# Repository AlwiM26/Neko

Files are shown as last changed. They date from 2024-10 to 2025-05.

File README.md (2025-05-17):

# Neko

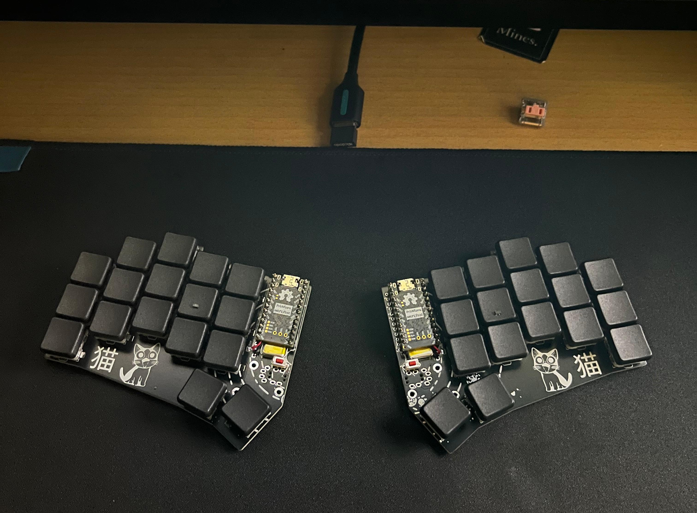
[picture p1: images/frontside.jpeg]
Neko keyboard


A custom version of the [Chocofi keyboard](https://github.com/pashutk/chocofi). With slightly different edge cut and added custom silkscreen.

## List of changes

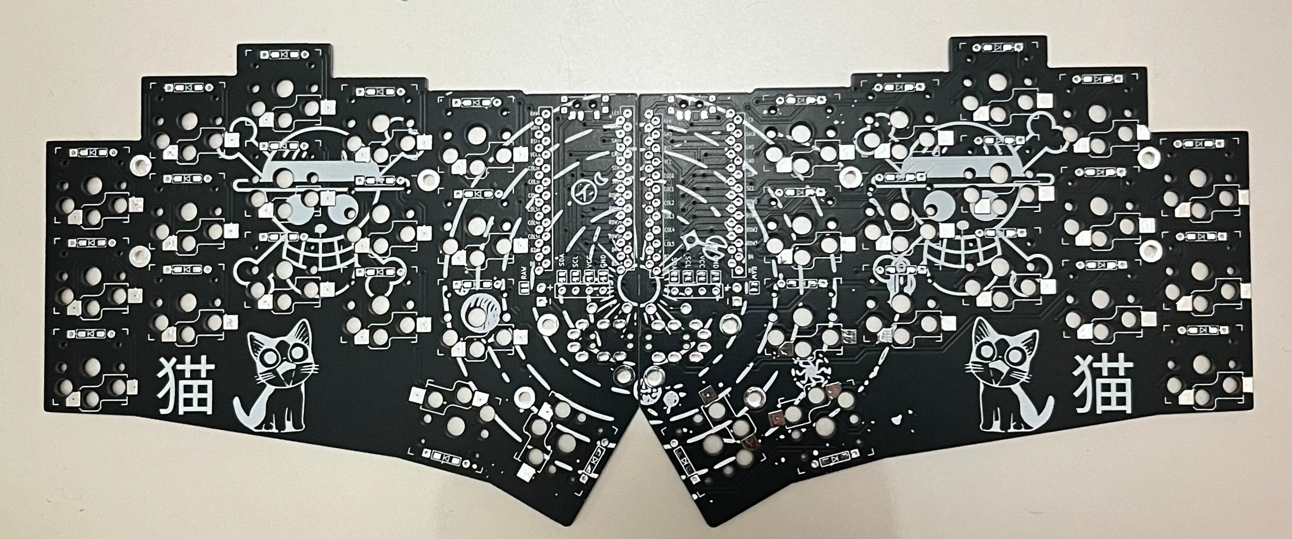
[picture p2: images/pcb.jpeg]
Neko pcb


- Slight change from the original edge cut
- Remove the inner ( 3rd ) thumb key
- Add some graphic for the silkscreen

## Assembly

- Solder all the diode on the bottom side, make sure to solder it to the correct orientation like this
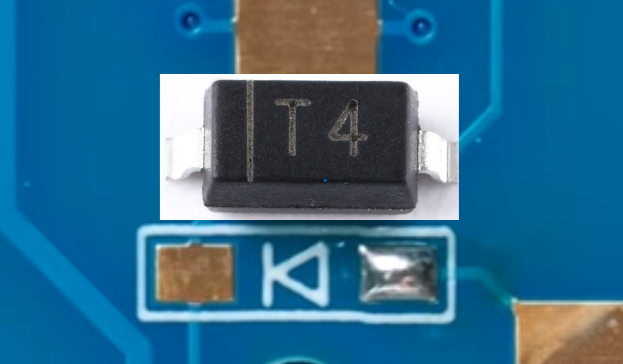
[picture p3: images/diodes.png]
Diode orientation
  
- Solder all the kailh hotswap socket on the bottom side
- ( Optional for **wireless** build )Solder power switch on the bottom side, after that, make sure to switch it off so that nothing happen when we solder the battery
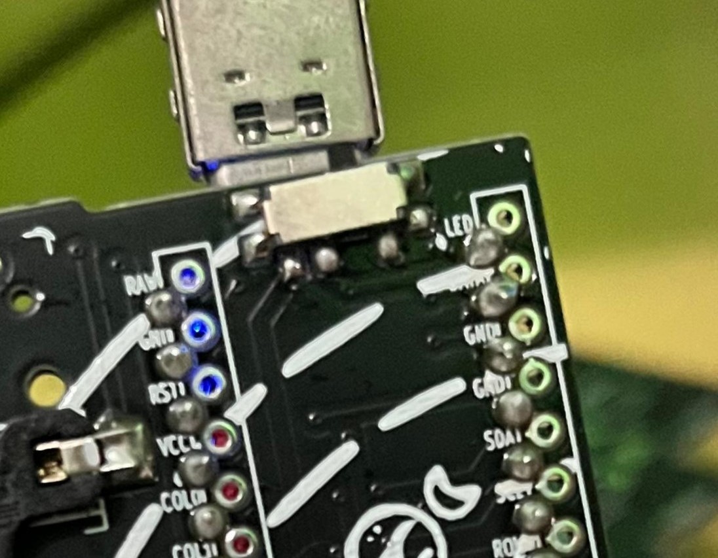
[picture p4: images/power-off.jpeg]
Power switch
  
- Solder the reset switch on the top side
- ( Optional for **wired** build) Solder the TRRS connector on the top side
- Solder the controller hotswap socket on the top side
- Solder the hotswap pin to the controller
- Remove the controller from the hotswap socket
- ( Optional for **wireless** build ) _Carefully_ solder battery wires to the connector, ensuring not to short the wires together, secure the other wire with masking tape, solder the black wire to the negative pad, and red wire to the positive pad
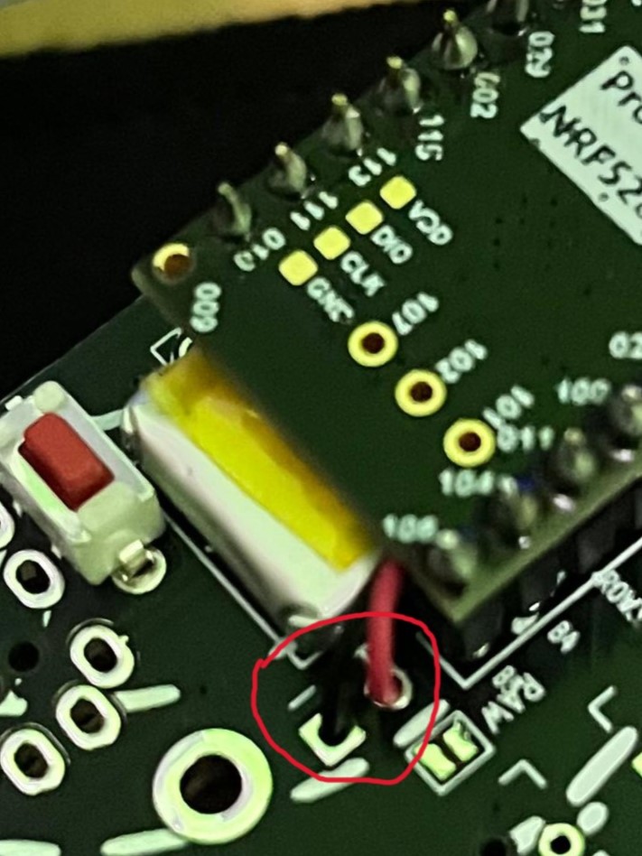
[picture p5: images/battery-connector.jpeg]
Battery socket
  
- ( Optional for **wireless** build ) Solder the battery Jumper ( labeled as RAW ) on the bottom side
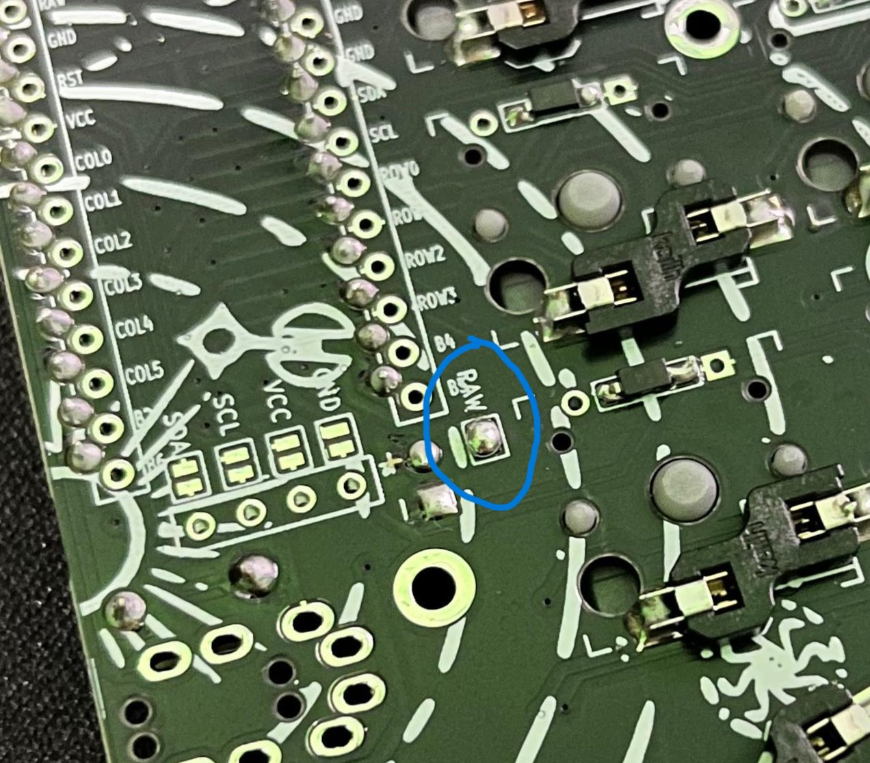
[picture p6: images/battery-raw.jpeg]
RAW
  

If you using a wireless controller, you can download my firmware [here](https://github.com/AlwiM26/zmk-config-neko/actions), or you can build your own firmware using the [ZMK firmware](https://zmk.dev), and edit the keymap using the [Keymap editor](https://nickcoutsos.github.io/keymap-editor/) by Nickcoutsos. If you using a wired controller, you can use [QMK firmware](https://qmk.fm/), and edit the layout using [Via app](https://www.caniusevia.com/)

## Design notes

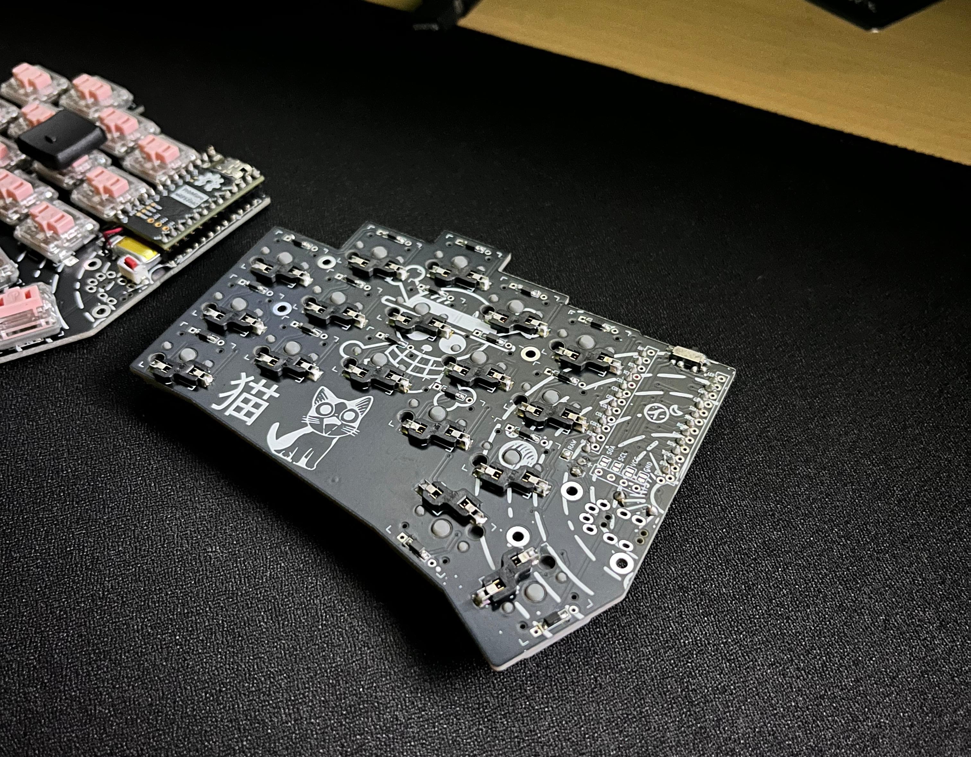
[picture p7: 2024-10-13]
images/backside.jpeg

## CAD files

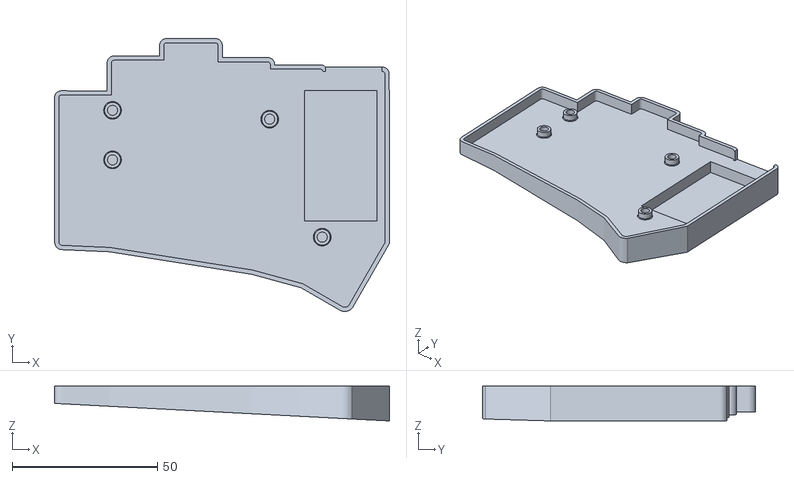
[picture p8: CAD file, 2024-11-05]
case/neko-battery-left.stl
115.2 x 93.8 x 12.0

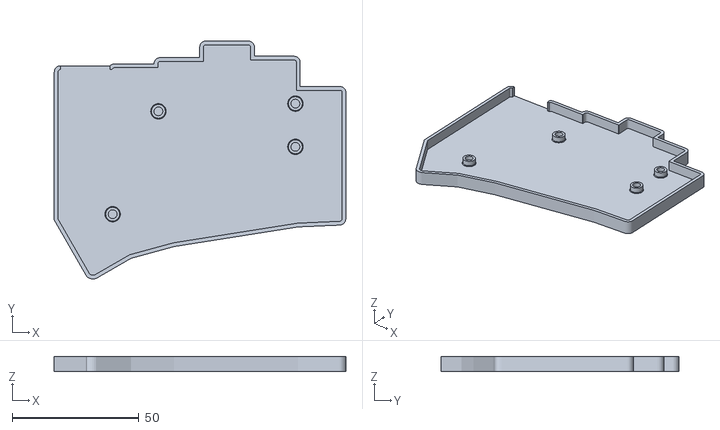
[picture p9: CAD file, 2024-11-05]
case/neko-right.stl
115.2 x 93.8 x 6.00

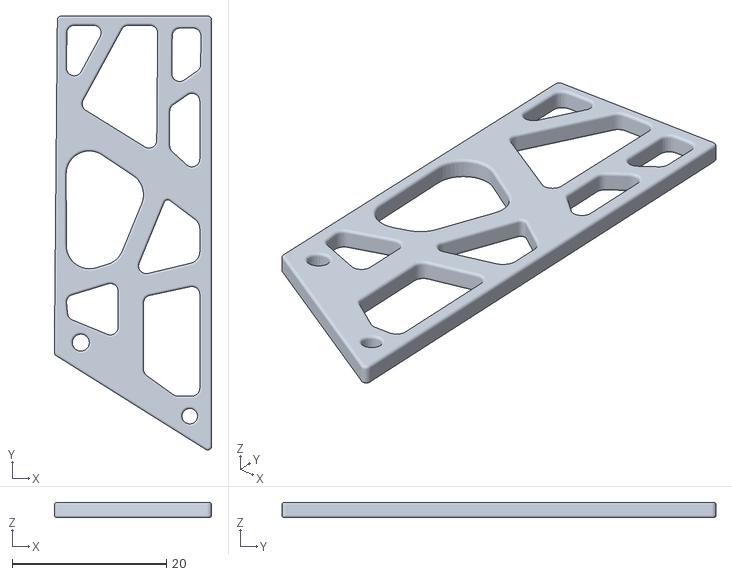
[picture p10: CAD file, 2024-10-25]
case/neko-cover.stl
20.4 x 56.2 x 2.00

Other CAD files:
case/neko-battery-right.stl
case/neko-left.stl

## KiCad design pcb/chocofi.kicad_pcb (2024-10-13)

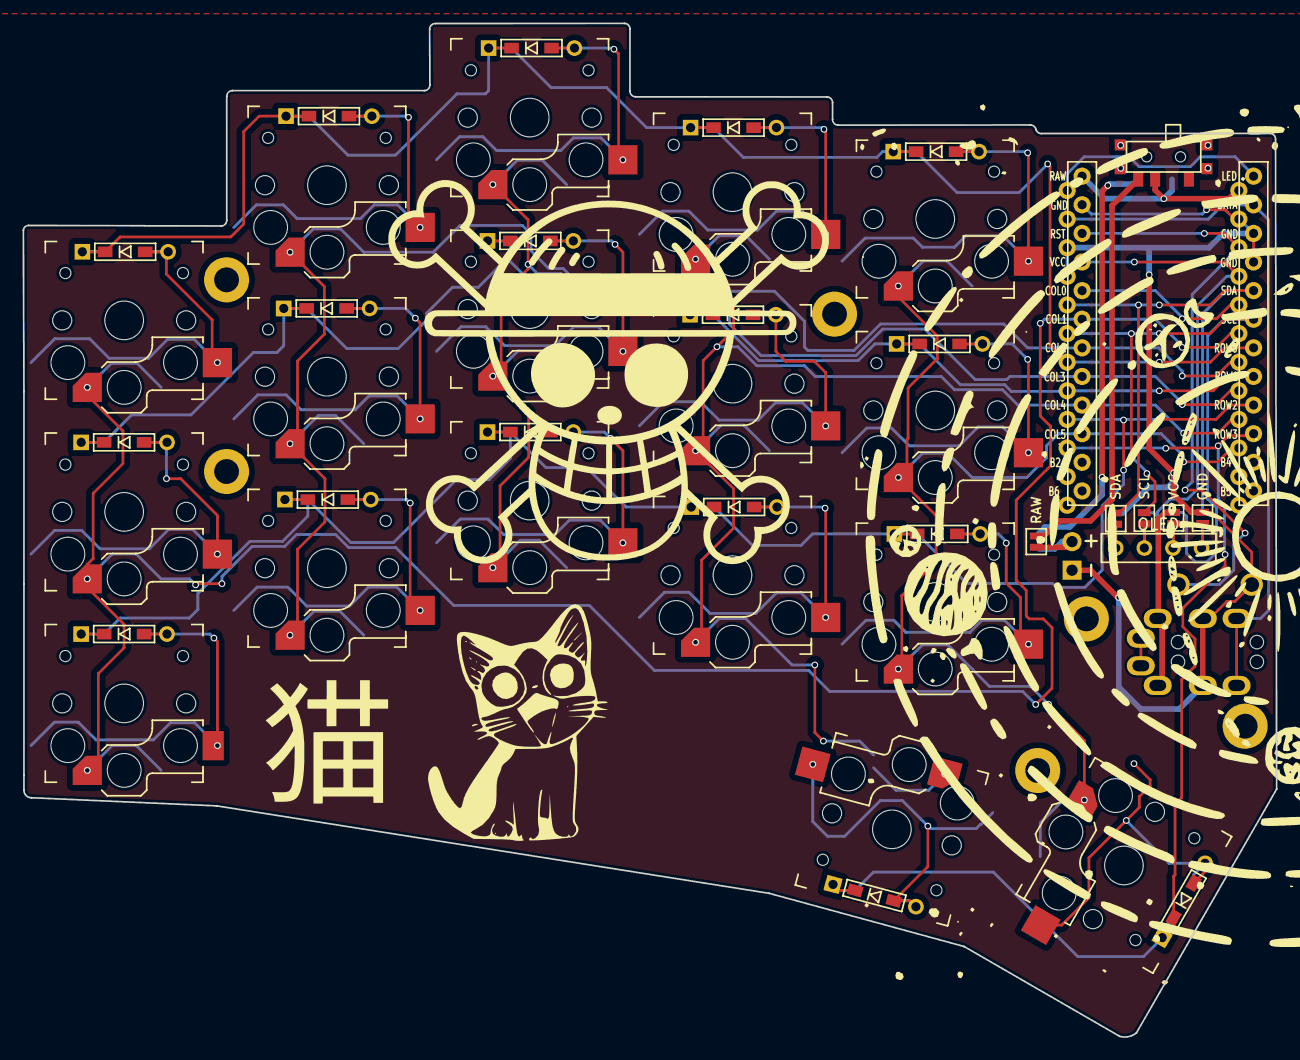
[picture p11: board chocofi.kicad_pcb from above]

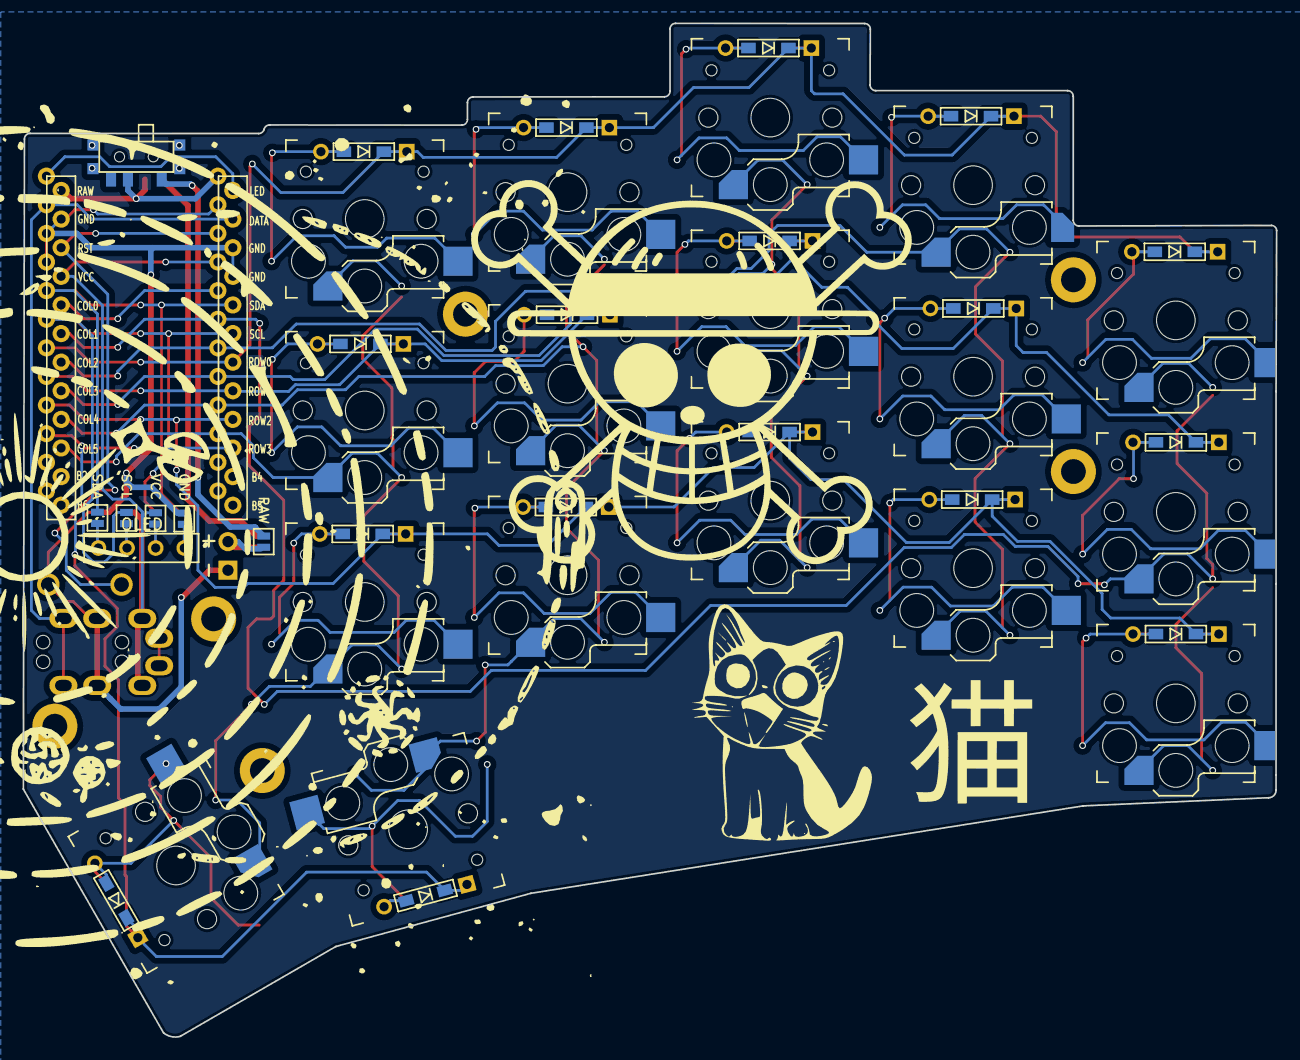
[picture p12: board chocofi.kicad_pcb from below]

Board: 2 copper layers, 111.3 x 90.0 mm, 57 parts (6 on the bottom side), 39 nets.

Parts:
D2, D3, D4, D5, D6, D8, D9, D10, D11, D12, D14, D15, D16, D17, D18, D20, D21: D; D3_TH_SMD
H1: h1; LEGO_HOLE
J1: MJ-4PP-9
J2: OLED
J3: Conn_01x02_Female; Battery_TH
JP6, JP61: SDA; Jumper
JP61#2, JP62#2: RAW; Jumper
JP62, JP68: GND; Jumper
JP63, JP66: SCL; Jumper
JP64, JP65: VCC; Jumper
RSW1: Val**; ResetSW
SW1, SW2#2: SW_SPDT; SW_SPDT+H-MSK12C01_hor(7pin_SMD)
SW2, SW3, SW4, SW5, SW6, SW8, SW9, SW10, SW11, SW12, SW14, SW15, SW16, SW17, SW18, SW20, SW21: SW_PUSH; Kailh_socket_PG1350_reversible
U1: ProMicro; ProMicro_v2
h2: h2; LEGO_HOLE
h3: h3; LEGO_HOLE
h5: h5; LEGO_HOLE
h6: h6; LEGO_HOLE
h7: h7; LEGO_HOLE

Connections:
BAT_PLUS: J3.2, JP61#2.2, JP62#2.2
GND: J1.C, J3.1, JP62.1, JP68.1, RSW1.1, U1.3, U1.4, U1.23
unnamed: D2.2, SW2.2
unnamed: D3.2, SW3.2
unnamed: D4.2, SW4.2
unnamed: D5.2, SW5.2
unnamed: D6.2, SW6.2
unnamed: D8.2, SW8.2
unnamed: D9.2, SW9.2
unnamed: D10.2, SW10.2
unnamed: D11.2, SW11.2
unnamed: D12.2, SW12.2
unnamed: D14.2, SW14.2
unnamed: D15.2, SW15.2
unnamed: D16.2, SW16.2
unnamed: D17.2, SW17.2
unnamed: D18.2, SW18.2
unnamed: D20.2, SW20.2
unnamed: D21.2, SW21.2
unnamed: J2.3, JP65.2, JP66.2
unnamed: J2.4, JP6.2, JP68.2
unnamed: J2.2, JP63.2, JP64.2
unnamed: J2.1, JP61.2, JP62.2
unnamed: SW1.2 (B), SW2#2.2 (B), U1.24
SCL: JP63.1, JP66.1, U1.6
SDA: JP6.1, JP61.1, U1.5
SW_RAW_2: JP61#2.1, SW1.3 (C)
VCC: J1.D, JP64.1, JP65.1, U1.21
col1: SW2.1, SW8.1, SW14.1, U1.19
col2: SW3.1, SW9.1, SW15.1, U1.18
col3: SW4.1, SW10.1, SW16.1, U1.17
col4: SW5.1, SW11.1, SW17.1, SW20.1, U1.16
col5: SW6.1, SW12.1, SW18.1, SW21.1, U1.15
data: J1.B, U1.2
reset: RSW1.2, U1.22
row0: D2.1, D3.1, D4.1, D5.1, D6.1, U1.7
row1: D8.1, D9.1, D10.1, D11.1, D12.1, U1.8
row2: D14.1, D15.1, D16.1, D17.1, D18.1, U1.9
row3: D20.1, D21.1, U1.10

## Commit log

2024-10-13 add gerber file
2024-10-13 Adding kicad project file
    [chocofi.kicad_pcb]
2024-10-22 Add backplate and case
    [neko-left.stl, neko-right.stl]
2024-10-23 add case file
    [NekoV1.f3d]
2024-10-23 Added case with battery support
    [NekoV1.f3d, neko-battery-left.stl, neko-battery-right.stl]
2024-10-25 Add controller cover
    [neko-cover.stl]
2024-10-26 fix readme, cleaning up
    [chocofi.kicad_pcb, neko-battery-left.stl, neko-battery-right.stl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]
2024-11-05 Fix the case fitting
    [neko-battery-left.stl, neko-battery-right.stl, neko-left.stl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]
